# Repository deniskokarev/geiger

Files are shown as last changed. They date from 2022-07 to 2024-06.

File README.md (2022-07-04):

# Geiger counter project

STM32 microcontroller project measuring radioation. Using

- STM32 Nucleo board
- STM X-Nucleo IDB05A2 bluetooth shield
- SBM-20 tube

**NB** using STM submodules, so checkout in `git clone --recursive` fashion.

The hardware is in the Nucleo (Arduino) shield form-factor

Exporting the readings over Blutooth to a Wearable Android client.

- [Hardware](./hardware) DipTrace schematics and layout for high-voltage and sensor shield
- [Firmware](./firmware) CubeMX + CLion project
- [Wearable Client](./client/android) Android Studio project for wearable client

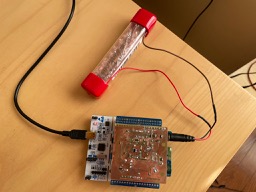
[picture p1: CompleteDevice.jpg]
Complete Device


Inspired by [Mighty Ohm Geiger kit](https://mightyohm.com/blog/products/geiger-counter/)

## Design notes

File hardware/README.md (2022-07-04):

# Geiger counter shield

The high-voltage supply is based on ~4kHz PWM signal coming from MC. PWM signal constantly running, but the high-voltage transistor is not. There is an OpAmp-based voltage sensor, which suppresses PWM and saves energy. 

It makes about ~3 PWM impulses per second sustaining ~400V with minimal effort.

DipTrace was used to compose schematic and board layout.

There are Eagle schematics and board files attached as well.

Also, LTSpice simulation file with opamp feedback loop calculations.

**TODO**

The voltage sensor is using BJT transistor as the first stage, which is very temperature sensitive. Must rework the schematic to avoid relying on the transistor.

MC gets EXTI interrupts on voltage below - this occrs about once a second so we can turn PWM timer off entirely.

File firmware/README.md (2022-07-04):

# Firmware

STM32 CubeMX-based project. One can customize geiger.ioc for another STM32 Chip/board/clock/pins and re-generate the code.
*(need to recover app_bluenrg_ms.c for now)* 
```
git checkout BlueNRG_MS/App/app_bluenrg_ms.c
```

Start CubeMX on Mac:
```
JAVA=/Library/Java/JavaVirtualMachines/jdk-11.0.12.jdk/Contents/Home/bin/java
exec $JAVA -Xmx2g -jar /Applications/STMicroelectronics/STM32CubeMX.app/Contents/Resources/STM32CubeMX
```

The code is written with STM32 HAL library using CLion and relatovely agnostic to the exact chip model.

Start CLion with ARM toolchain in the PATH:
```
export PATH=$PATH:/Applications/ARM/bin
open /Applications/CLion.app
```

Build:
```
export PATH=$PATH:/Applications/ARM/bin
mkdir cmake-build-release
cd cmake-build-release
cmake -DCMAKE_BUILD_TYPE=Release ..
cmake --build . --parallel 8
```

Flash using st-link
```
st-flash write geiger.bin 0x8000000
```

Flash using openocd
```
#openocd -f board/st_nucleo_f4.cfg -c "program geiger.elf" -c reset -c shutdown
```

## TODO

Use uniq device name

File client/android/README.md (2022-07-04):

# Wearable OS client

Build:

```
./gradlew assembleDebug
```

Install:
```
./gradlew installDebug
```

Run:

Tap on the GeigerCounter application and permit it accessing Bluetooth permissions. It may start and complain about no BT permissions. Then close and start again. It should ask for permissions. Answer yes and it'll close the app. Then start it again and it should work fine.

Uninstall:
```
adb uninstall dkv.geigercounter
```

TODO:
- Use uniq device name

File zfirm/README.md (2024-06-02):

# TODO
The Shell doesn't react. Probably inbound UART doesn't work

Remove Settings from prj.conf to save program size

# Build
Install Zephyr as per [Getting Started Guide](https://docs.zephyrproject.org/latest/develop/getting_started/index.html)

Setup environment
```
. ./zephyr.env
cmake -B cmake-build-debug .
alias b="(cmake --build cmake-build-debug -- -j16)"
```

Develop and rebuild using
```
b
```

# Flash

Use `st-util`
```
brew install stlink
```

Setup environment
```
alias f="st-flash --connect-under-reset write cmake-build-debug/zephyr/zephyr.bin 0x8000000"
```

Flash after build with
```
f
```

# Run
```
screen /dev/cu.usbserial-D30DTADJ 115200
exit ^k

or

picocom -b 115200 /dev/cu.usbmodem14D42403
exit ^a ^x
```

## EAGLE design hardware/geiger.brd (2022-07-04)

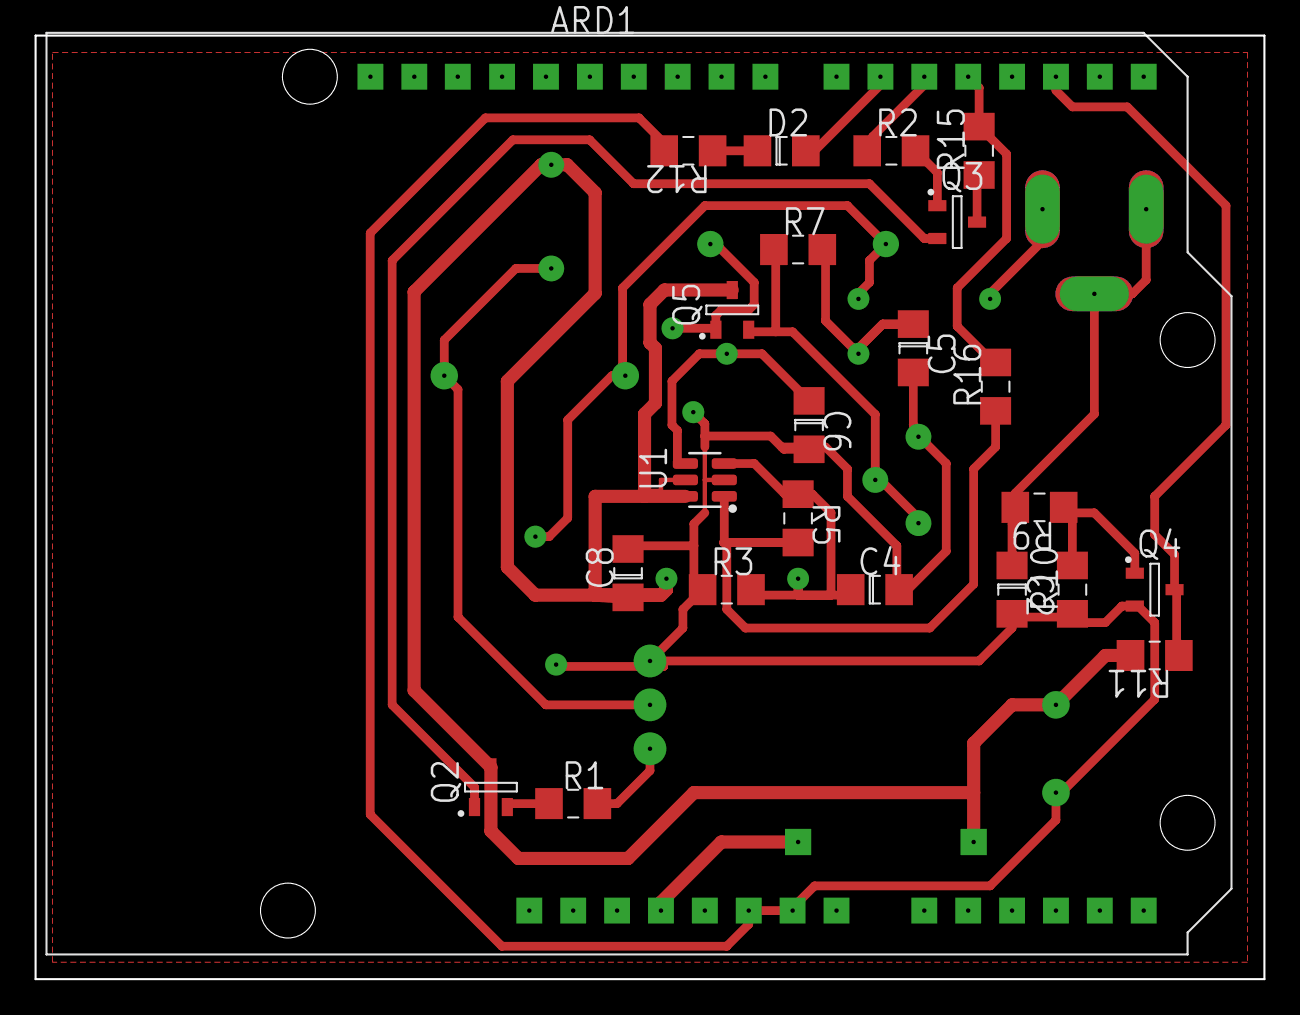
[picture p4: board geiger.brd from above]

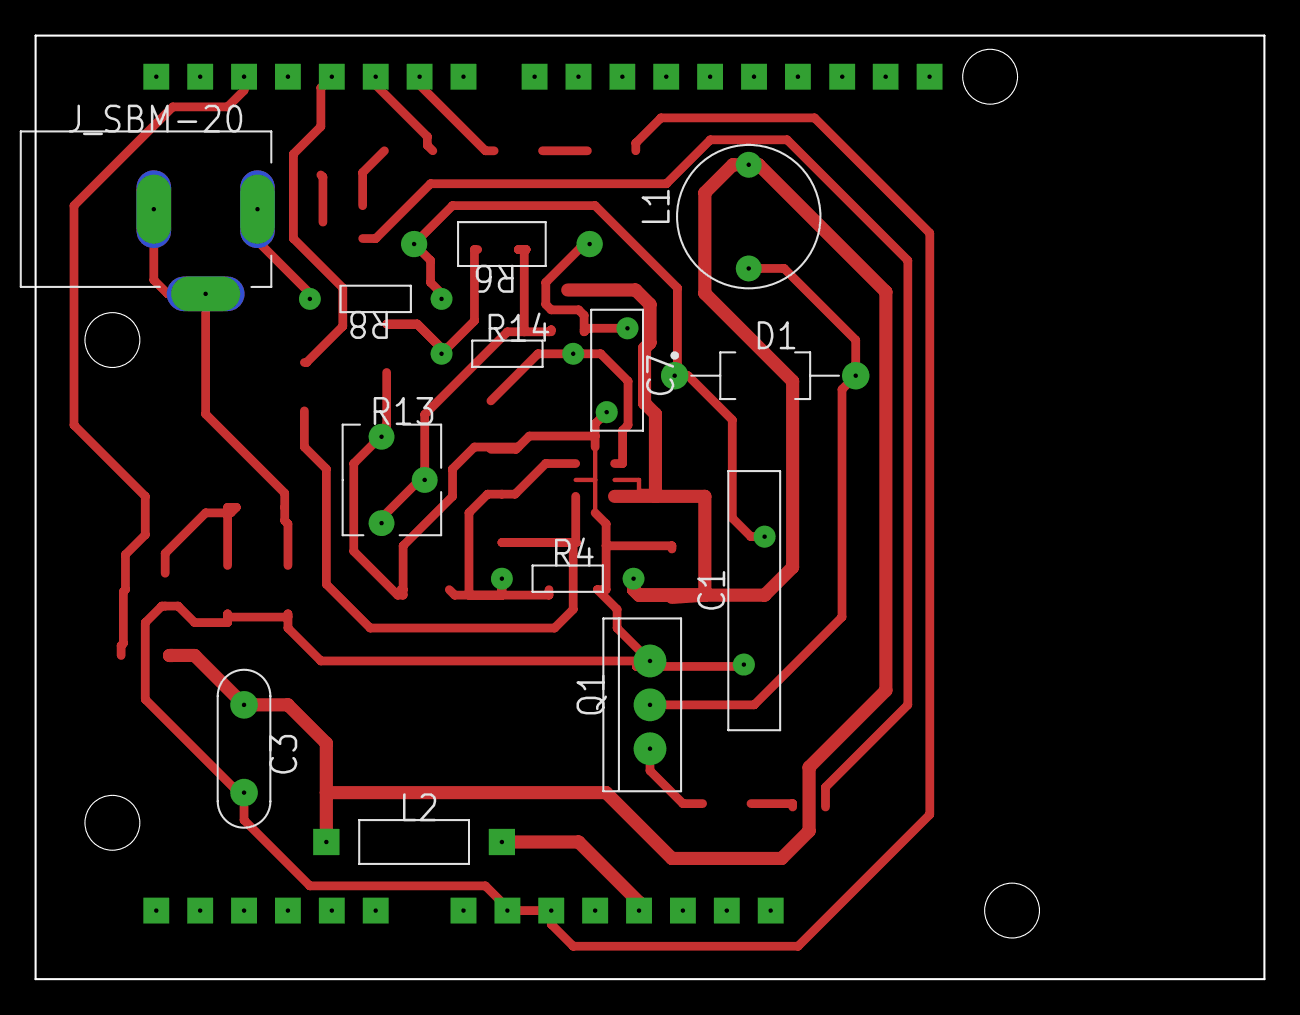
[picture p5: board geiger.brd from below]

Board: 2 copper layers, 71.1 x 54.6 mm, 36 parts (13 on the bottom side), 24 nets.

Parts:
ARD1: ARDUINO UNO; ADRUINO_UNO
C1: .005u; CAPRB740W60L1500T300H1800
C2: 220pF; CAP_1206
C3: 220u; CAP-5.08/9.15x3
C4: 104; CAP_1206
C5, C6: 1n; CAP_1206
C7: 0.1uF; CAPRB485W60L700T300H1000
C8: 1u; CAP_1206
D1: 1N4937G; DIOAD1048W78L520D270_AD2
D2: LED_1206; DIO_1206
J_SBM-20: 644456-2; 4840-2211
L1: 6100-103K-RC; BOURNS_6100-100K
L2: 100nH; IND_400
Q1: FJP5027RTU; TO-220
Q2, Q3, Q4, Q5: MMBT3904; SOT23
R1, R12: 220; RES_1206
R2, R3, R10: 100k; RES_1206
R4: 100k; RES-7.62/4x1.5
R5: 10M; RES_1206
R6: 5GOhm; RES-10.16/5.1x2.5
R7: 1M; RES_1206
R8: 4.7M; RES-7.62/4x1.5
R9: 22k; RES_1206
R11: 10k; RES_1206
R13: 500k; 306X
R14: 1M; RES-7.62/4x1.5
R15: 1k; RES_1206
R16: 1; RES_1206
U1: OPA341NA; SOT23-6P95_270X145L35X35M

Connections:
CTL: R5.2, R16.1, U1.1
GND: ARD1.GND2, ARD1.GND3, C1.1, C2.2, C3.2, C4.2, C5.2, C6.2, C7.2, C8.2, Q1.3, Q4.2, R3.1, R10.1, R12.2, R13.1, U1.2
HI: J_SBM-20.1, R8.2
HI_DANGER: C1.2, D1.1, R6.2, R8.1
Half_With_Histeresis: C4.1, R3.2, R4.1, R5.1, U1.3
Hi_Sensor: C6.1, R14.2, U1.4
NOUT: ARD1.2, Q4.3, R11.1
Net_2: D1.2, L1.1, Q1.2
Net_3: Q2.1, Q3.2
Net_4: Q1.1, R1.2
Net_5: Q2.2, R1.1
Net_6: Q3.1, R2.2
Net_11: C7.1, Q5.1, R6.1
Net_12: C2.1, J_SBM-20.2, J_SBM-20.3, R9.2
Net_13: Q4.1, R9.1, R10.2
Net_16: ARD1.3.3V, L2.2
Net_17: D2.1, R12.1
Net_18: ARD1.6, D2.2
Net_20: C5.1, R7.2, R14.1
Net_21: Q5.2, R7.1, R13.2, R13.3
Net_22: Q3.3, R15.1
Net_23: ARD1.4, R15.2, R16.2
PWM: ARD1.5, R2.1
VCC: C3.1, C8.1, L1.2, L2.1, Q2.3, Q5.3, R4.2, R11.2, U1.5, U1.6

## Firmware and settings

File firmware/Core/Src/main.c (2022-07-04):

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
/* Includes ------------------------------------------------------------------*/
#include "main.h"
#include "app_bluenrg_ms.h"

/* USER CODE BEGIN Includes */
#include <stdio.h>
#include "ring_buffer.h"
/* USER CODE END Includes */

TIM_HandleTypeDef htim1;
TIM_HandleTypeDef htim2;
TIM_HandleTypeDef htim3;

/* USER CODE BEGIN PV */
// updated from htim1 interrupt handler, which triggers every second
uint64_t seconds_since_boot = 0;

uint64_t time_since_boot_ms() {
    // htim1 timer is counting in 1/10_000 secs
    return seconds_since_boot * 1000 + __HAL_TIM_GetCounter(&htim1) / 10;
}

// our Clicks Per Minute metric
float cpm = 0;

// Clicks Per Minute will be based on 31 last values
#define RB_SZ 32
struct tagRB {
    RING_BUFFER rb;
    RB_NUM_T ring_buffer_data[RB_SZ];
} RB;

RING_BUFFER *ring_buffer = (RING_BUFFER*)&RB;

/* USER CODE END PV */

void SystemClock_Config(void);
static void MX_GPIO_Init(void);
static void MX_TIM3_Init(void);
static void MX_TIM2_Init(void);
static void MX_TIM1_Init(void);
/**
  * @brief  The application entry point.
  * @retval int
  */
int main(void)
{
  /* MCU Configuration--------------------------------------------------------*/

  /* Reset of all peripherals, Initializes the Flash interface and the Systick. */
  HAL_Init();

  /* Configure the system clock */
  SystemClock_Config();

  /* Initialize all configured peripherals */
  MX_GPIO_Init();
  MX_TIM3_Init();
  MX_TIM2_Init();
  MX_TIM1_Init();
  MX_BlueNRG_MS_Init();
  /* USER CODE BEGIN 2 */
  HAL_TIM_PWM_Start(&htim3, TIM_CHANNEL_1);
  rb_init(ring_buffer, RB_SZ);
  // htim1 is our system time counter, interrupts every second and counts with 1/10_000 sec discretization
  HAL_TIM_OC_MspInit(&htim1);
  HAL_TIM_Base_Start_IT(&htim1);

  /* USER CODE END 2 */

  /* Infinite loop */
  /* USER CODE BEGIN WHILE */
  while (1)
  {
    /* USER CODE END WHILE */

  MX_BlueNRG_MS_Process();
    /* USER CODE BEGIN 3 */
  }
  /* USER CODE END 3 */
}

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
/* USER CODE BEGIN 4 */
void HAL_GPIO_EXTI_Callback(uint16_t GPIO_Pin) {
    if (GPIO_Pin == GEIGER_EXTI_NEW_Pin) {
        uint64_t tnow = time_since_boot_ms();
        rb_put(ring_buffer, tnow);
        int cnt = rb_count(ring_buffer);
        uint64_t t_first = rb_first(ring_buffer);
        uint64_t tdiff = tnow - t_first;
        if (tdiff > 0) {
            cpm = cnt * 1000.0 * 60 / tdiff;
            printf("Tick at time: %lld ms, t_first = %lld, cnt = %d\r\n", tnow, t_first, cnt);
            printf("CPM: %.02f\r\n", cpm);
        }
        // TIM2CH3 is configured in 0.1 sec one-pulse to LED indicator. Making that one flash
        HAL_TIM_PWM_Init(&htim2);
        HAL_TIM_PWM_Start(&htim2, TIM_CHANNEL_3);
    }
}

void HAL_TIM_PeriodElapsedCallback(TIM_HandleTypeDef *htim) {
    if (htim->Instance == TIM1) {
        // our system time
        seconds_since_boot++;
    }
}

/* USER CODE END 4 */
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


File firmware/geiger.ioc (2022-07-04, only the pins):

Mcu.UserName=STM32F401RETx
PA0-WKUP.Signal=GPXTI0
PA1.Signal=GPIO_Output
PA10.GPIO_Label=GEIGER_EXTI_NEW
PA10.Signal=GPXTI10
PA13.GPIO_Label=TMS
PA13.Signal=SYS_JTMS-SWDIO
PA14.GPIO_Label=TCK
PA14.Signal=SYS_JTCK-SWCLK
PA2.GPIO_Label=USART_TX
PA2.Signal=USART2_TX
PA3.GPIO_Label=USART_RX
PA3.Signal=USART2_RX
PA5.Signal=GPIO_Output
PA6.Signal=SPI1_MISO
PA7.Signal=SPI1_MOSI
PA8.Signal=GPIO_Output
PA9.GPIO_Label=GEIGER_EXTI
PA9.Signal=GPXTI9
PB10.GPIO_Label=TIM_LED
PB10.Signal=S_TIM2_CH3
PB3.Signal=SPI1_SCK
PB4.GPIO_Label=TIM3_CH1_PWM
PB4.Signal=S_TIM3_CH1
PB5.GPIO_Label=CTL_EXTI
PB5.Signal=GPXTI5
PC13-ANTI_TAMP.GPIO_Label=B1 [Blue PushButton]
PC13-ANTI_TAMP.Signal=GPXTI13
PC14-OSC32_IN.Signal=RCC_OSC32_IN
PC15-OSC32_OUT.Signal=RCC_OSC32_OUT

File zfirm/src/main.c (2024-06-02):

#include <zephyr/kernel.h>
#include <zephyr/logging/log.h>
#include <zephyr/settings/settings.h>

LOG_MODULE_REGISTER(geiger, 4);

#include "boost_drv.h"

int main(void) {
	if (!boost_drv_init()) {
		return -1;
	}
	LOG_INF("Boost driver initialization: OK");
	int rc = settings_subsys_init();
	if (rc) {
		LOG_ERR("settings subsys initialization: fail (err %d)", rc);
		return -2;
	}
	LOG_INF("Settings subsys initialization: OK");
	// ok to exit main, the shell thread keeps running
	return 0;
}

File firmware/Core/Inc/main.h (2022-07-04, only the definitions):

#define BSP_BUTTON_EXTI_IRQn EXTI15_10_IRQn
#define USART_TX_Pin GPIO_PIN_2
#define USART_TX_GPIO_Port GPIOA
#define USART_RX_Pin GPIO_PIN_3
#define USART_RX_GPIO_Port GPIOA
#define TIM_LED_Pin GPIO_PIN_10
#define TIM_LED_GPIO_Port GPIOB
#define GEIGER_EXTI_Pin GPIO_PIN_9
#define GEIGER_EXTI_GPIO_Port GPIOA
#define GEIGER_EXTI_EXTI_IRQn EXTI9_5_IRQn
#define GEIGER_EXTI_NEW_Pin GPIO_PIN_10
#define GEIGER_EXTI_NEW_GPIO_Port GPIOA
#define GEIGER_EXTI_NEW_EXTI_IRQn EXTI15_10_IRQn
#define TMS_Pin GPIO_PIN_13
#define TMS_GPIO_Port GPIOA
#define TCK_Pin GPIO_PIN_14
#define TCK_GPIO_Port GPIOA
#define TIM3_CH1_PWM_Pin GPIO_PIN_4
#define TIM3_CH1_PWM_GPIO_Port GPIOB
#define CTL_EXTI_Pin GPIO_PIN_5
#define CTL_EXTI_GPIO_Port GPIOB
#define CTL_EXTI_EXTI_IRQn EXTI9_5_IRQn

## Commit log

2022-05-08 fixing my ARM toolchain path
2022-05-09 fixing CubeMX config for the board
    [geiger.ioc]
2022-05-09 fixing SPI1 and re-rendering
    [main.c, main.h]
2022-05-10 changing CubeMX BlueNRG project to SensorDemo
2022-05-14 !!! working bluenrg sensor demo
2022-05-22 Add TIM4 1Hz timer
2022-05-22 Make time_since_boot in milliseconds
2022-05-23 Populate CPM over ST BLE as pressure
2022-06-20 Add PWM output, remove unused timer
2022-07-01 Added Geiger_New sensor pin PA10
2022-07-01 making PWM 4kHz
2022-07-04 Add LED 0.1sec blink on the geiger counter event
2022-07-04 adding comments for LED blink
2022-07-04 Moved firmware code to its own dir
    [geiger_shield2_Top.gbr]
2022-07-04 adding Eagle schematics and board
    [geiger.brd, geiger.sch]
2024-06-02 adding pwm functionality to Zephyr fw

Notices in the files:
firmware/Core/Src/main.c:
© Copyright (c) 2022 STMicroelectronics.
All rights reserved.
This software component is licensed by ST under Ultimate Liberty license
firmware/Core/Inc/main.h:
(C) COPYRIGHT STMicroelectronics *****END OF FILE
